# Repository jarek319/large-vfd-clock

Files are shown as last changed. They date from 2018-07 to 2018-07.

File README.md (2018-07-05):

# large-vfd-clock
The largest VFDs I can get my hands on make a really nice clock!

The ILC1-1/8L was another interesting specimen I found while trawling ebay for strange displays.

4 of them with another VFD tube for the colon connect to a Wifi-enabled microcontroller for timekeeping.

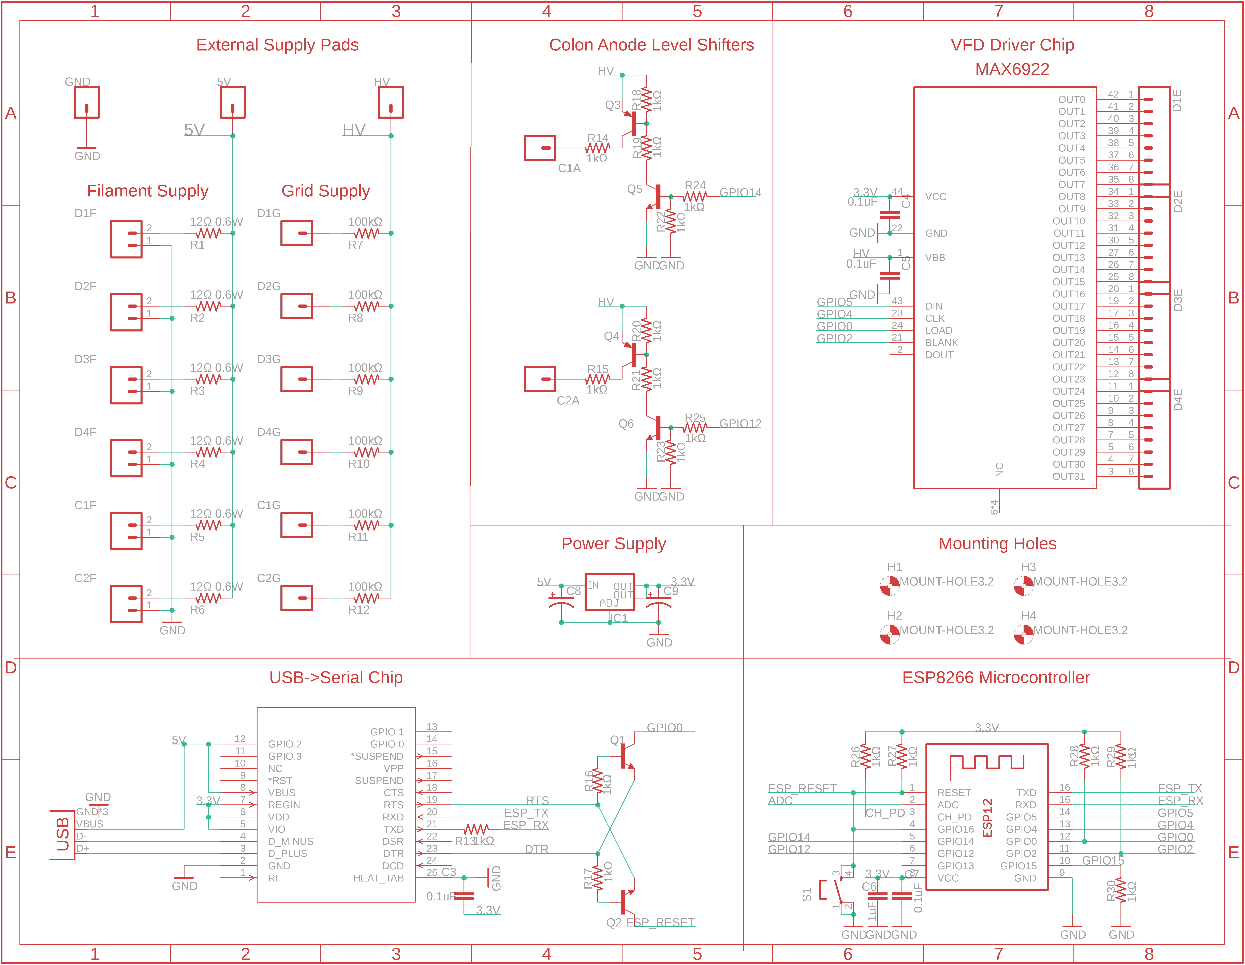
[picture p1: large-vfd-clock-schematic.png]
schematic

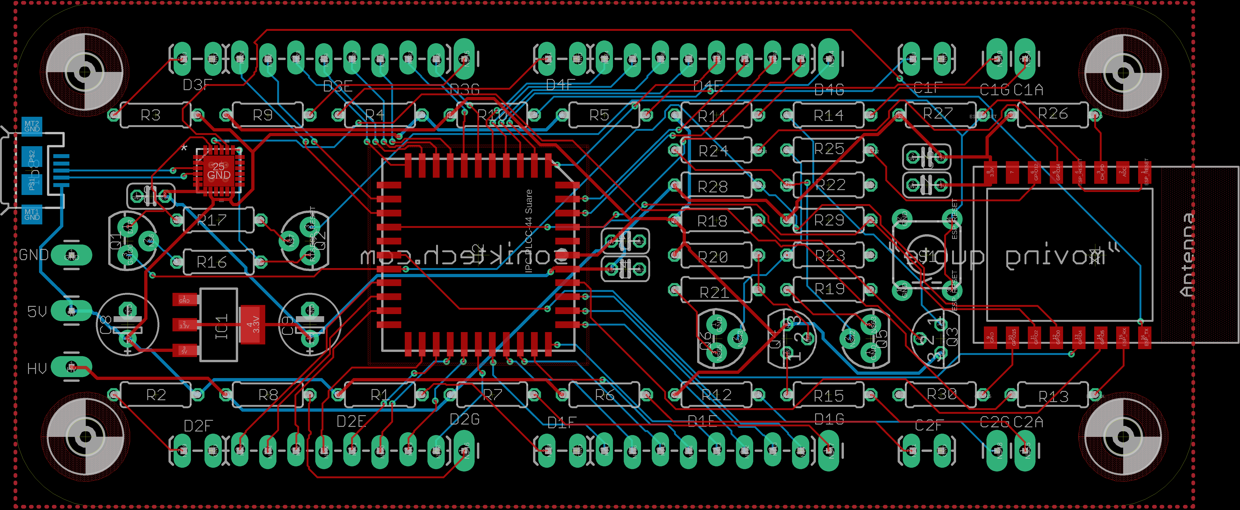
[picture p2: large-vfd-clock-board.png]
board


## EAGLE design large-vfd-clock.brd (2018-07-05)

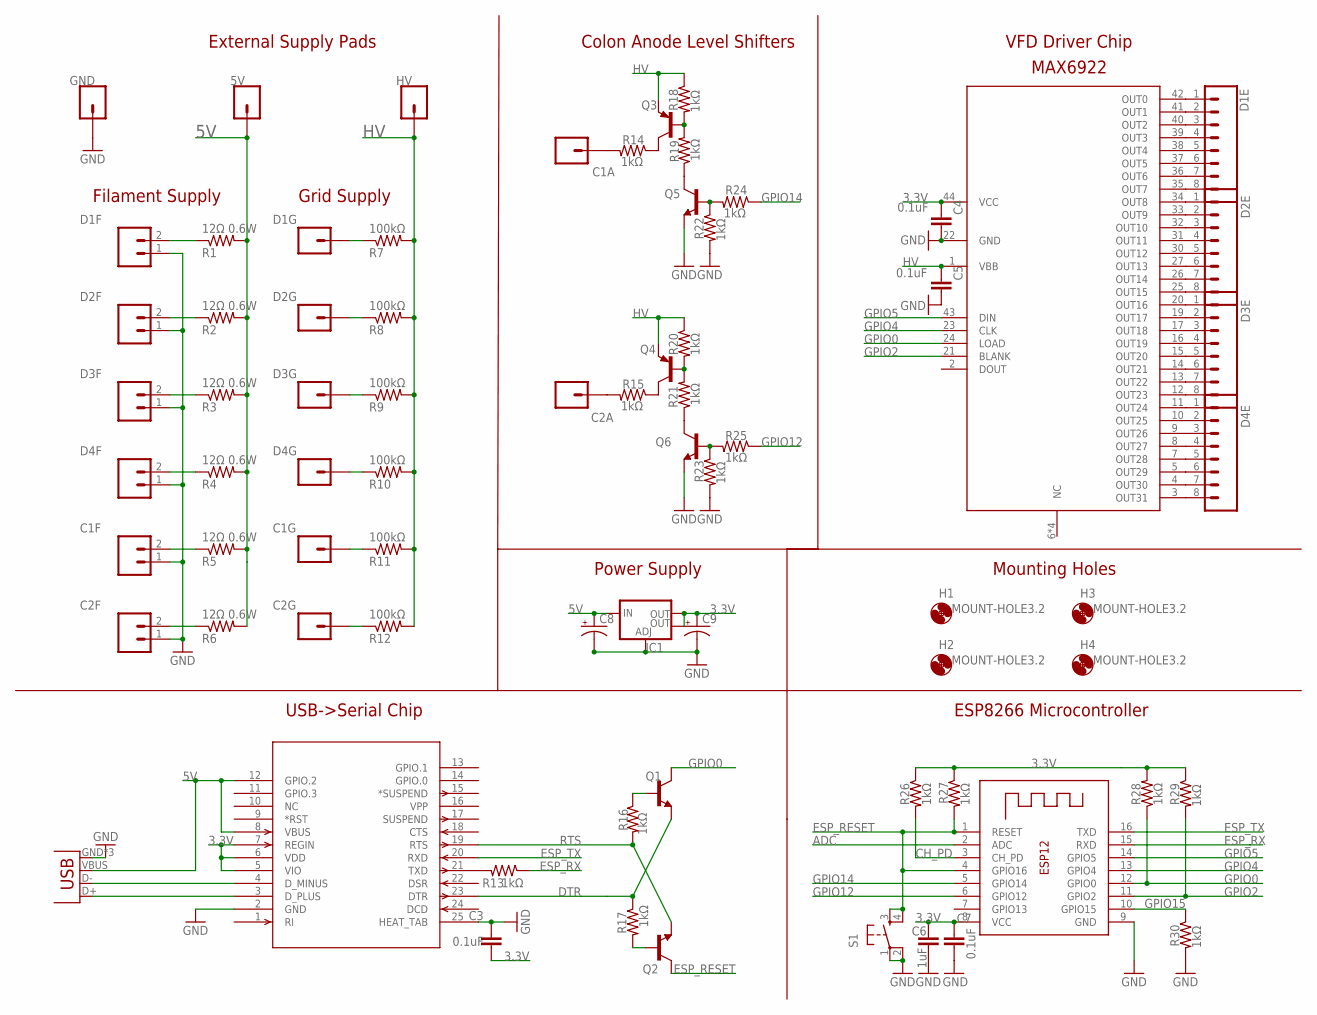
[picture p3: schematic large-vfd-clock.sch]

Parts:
5V: M01PTH_LONGPAD; 1X01_LONGPAD
C1A, C1G, C2A, C2G: M01PTH_LONGPAD; 1X01_LONGPAD
C1F, C2F: M02LOCK_LONGPADS; 1X02_LOCK_LONGPADS
C3, C4, C5, C7: 0.1uF; C025-024X044
C6: 1uF; C025-024X044
C8, C9: CPOL-USE2,5-6E; E2,5-6E
D1E, D2E, D3E, D4E: M08LOCK_LONGPADS; 1X08_LOCK_LONGPADS
D1F, D2F, D3F, D4F: M02LOCK_LONGPADS; 1X02_LOCK_LONGPADS
D1G, D2G, D3G, D4G: M01PTH_LONGPAD; 1X01_LONGPAD
GND: M01PTH_LONGPAD; 1X01_LONGPAD
H1, H2, H3, H4: MOUNT-HOLE3.2; 3,2
HV: M01PTH_LONGPAD; 1X01_LONGPAD
IC1: V_REG_LM1117SOT223; SOT223
JP8: SPARKFUN-CONNECTORS_USB-MICROB
Q1, Q2, Q5, Q6: MMBT2222A; TO-92
Q3, Q4: MMBT3906; TO92
R1, R2, R3, R4, R5, R6: 12Ω 0.6W; 0207/7
R7, R8, R9, R10, R11, R12: 100kΩ; 0207/7
R13, R14, R15, R16, R17, R18, R19, R20, R21, R22, R23, R24, R25, R26, R27, R28, R29, R30: 1kΩ; 0207/7
S1: TAC_SWITCHPTH; TACTILE-PTH
U1: CP2104-GM; QFN24_4X4
U2: MAX6922; PLCC44
X1: ESP-12

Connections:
3.3V: C3.2, C4.1, C6.1, C7.1, C9.+, IC1.2 (OUT), IC1.4 (OUT), R26.1, R27.1, R28.2, R29.1, U1.5 (VIO), U1.6 (VDD), U1.7 (REGIN), U2.44 (VCC), X1.8 (VCC)
5V: 5V.1, C8.+, IC1.3 (IN), JP8.VBUS, R1.2, R2.2, R3.2, R4.2, R5.2, R6.2, U1.8 (VBUS), U1.12 (GPIO.2)
ADC: X1.2 (ADC)
CH_PD: R26.2, X1.3 (CH_PD)
DTR: Q1.1 (E), R17.1, U1.23 (DTR)
D_N1: JP8.D-, U1.4 (D_MINUS)
D_P1: JP8.D+, U1.3 (D_PLUS)
ESP_RESET: Q2.3 (C), R27.2, S1.3, S1.4, X1.1 (RESET), X1.4 (GPIO16)
ESP_RX: R13.1, X1.15 (RXD)
ESP_TX: U1.20 (RXD), X1.16 (TXD)
GND: C1F.1, C2F.1, C3.1, C4.2, C5.2, C6.2, C7.2, C8.-, C9.-, D1F.1, D2F.1, D3F.1, D4F.1, GND.1, IC1.1 (ADJ), JP8.GND, JP8.MT1 (GND), JP8.MT2 (GND), Q5.1 (E), Q6.1 (E), R22.2, R23.2, R30.2, S1.1, S1.2, U1.2 (GND), U1.25 (HEAT_TAB), U2.22 (GND), X1.9 (GND)
GPIO0: Q1.3 (C), R28.1, U2.24 (LOAD), X1.12 (GPIO0)
GPIO2: R29.2, U2.21 (BLANK), X1.11 (GPIO2)
GPIO4: U2.23 (CLK), X1.13 (GPIO4)
GPIO5: U2.43 (DIN), X1.14 (GPIO5)
GPIO12: R25.1, X1.6 (GPIO12)
GPIO14: R24.1, X1.5 (GPIO14)
GPIO15: R30.1, X1.10 (GPIO15)
HV: C5.1, HV.1, Q3.3 (E), Q4.3 (E), R7.2, R8.2, R9.2, R10.2, R11.2, R12.2, R18.1, R20.1, U2.1 (VBB)
unnamed: R13.2, U1.21 (TXD)
unnamed: D1E.1, U2.42 (OUT0)
unnamed: Q1.2 (B), R16.1
unnamed: Q2.2 (B), R17.2
unnamed: D1E.2, U2.41 (OUT1)
unnamed: D1E.3, U2.40 (OUT2)
unnamed: D1E.4, U2.39 (OUT3)
unnamed: D1E.5, U2.38 (OUT4)
unnamed: D1E.6, U2.37 (OUT5)
unnamed: D1E.7, U2.36 (OUT6)
unnamed: D1E.8, U2.35 (OUT7)
unnamed: D2E.1, U2.34 (OUT8)
unnamed: D2E.2, U2.33 (OUT9)
unnamed: D2E.3, U2.32 (OUT10)
unnamed: D2E.4, U2.31 (OUT11)
unnamed: D2E.5, U2.30 (OUT12)
unnamed: D2E.6, U2.27 (OUT13)
unnamed: D2E.7, U2.26 (OUT14)
unnamed: D2E.8, U2.25 (OUT15)
unnamed: D3E.1, U2.20 (OUT16)
unnamed: D3E.2, U2.19 (OUT17)
unnamed: D3E.3, U2.17 (OUT18)
unnamed: D3E.4, U2.16 (OUT19)
unnamed: D3E.5, U2.15 (OUT20)
unnamed: D3E.6, U2.14 (OUT21)
unnamed: D3E.7, U2.13 (OUT22)
unnamed: D3E.8, U2.12 (OUT23)
unnamed: D4E.1, U2.11 (OUT24)
unnamed: D4E.2, U2.10 (OUT25)
unnamed: D4E.3, U2.9 (OUT26)
unnamed: D4E.4, U2.8 (OUT27)
unnamed: D4E.5, U2.7 (OUT28)
unnamed: D4E.6, U2.5 (OUT29)
unnamed: D4E.7, U2.4 (OUT30)
unnamed: D4E.8, U2.3 (OUT31)
unnamed: Q5.2 (B), R22.1, R24.2
unnamed: Q6.2 (B), R23.1, R25.2
unnamed: D4G.1, R10.1
unnamed: D3G.1, R9.1
unnamed: D2G.1, R8.1
unnamed: D1G.1, R7.1
unnamed: C2G.1, R12.1
unnamed: C1G.1, R11.1
unnamed: C1F.2, R5.1
unnamed: C2F.2, R6.1
unnamed: Q4.1 (C), R15.1
unnamed: Q3.1 (C), R14.1
unnamed: C1A.1, R14.2
unnamed: C2A.1, R15.2
unnamed: D1F.2, R1.1
unnamed: D2F.2, R2.1
unnamed: D3F.2, R3.1
unnamed: D4F.2, R4.1
unnamed: Q5.3 (C), R19.1
unnamed: Q3.2 (B), R18.2, R19.2
unnamed: Q6.3 (C), R21.1
unnamed: Q4.2 (B), R20.2, R21.2
RTS: Q2.1 (E), R16.2, U1.19 (RTS)

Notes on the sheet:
Filament Supply
Grid Supply
External Supply Pads
Colon Anode Level Shifters
Mounting Holes
VFD Driver Chip
MAX6922
Power Supply
USB->Serial Chip
ESP8266 Microcontroller

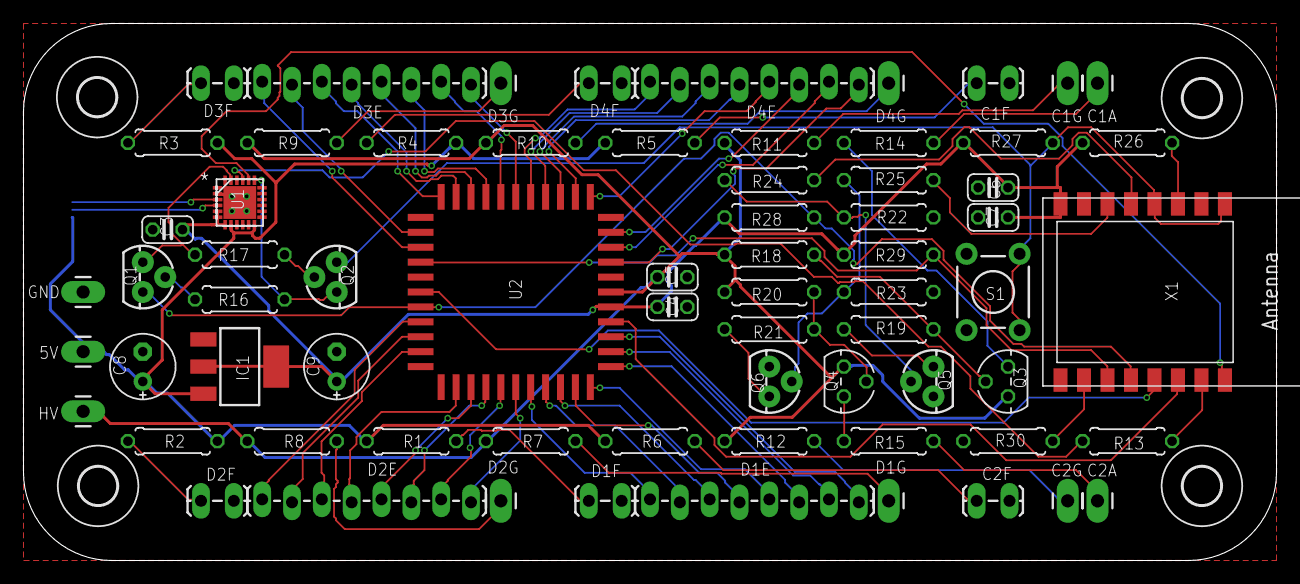
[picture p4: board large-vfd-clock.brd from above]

Board: 2 copper layers, 106.7 x 45.7 mm, 74 parts (1 on the bottom side), 76 nets.

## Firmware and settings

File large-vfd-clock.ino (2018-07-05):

#include <TimeLib.h>
#include <ESP8266WiFi.h>
#include <WiFiUdp.h>
extern "C" {
#include "user_interface.h"
}

#define TOPCOLON 14
#define BOTTOMCOLON 12
#define DIN 5
#define CLK 4
#define LOAD 0
#define BLANK 2

// NTP code adapted from ESP8266 Example code in Arduino core
char ssid[] = "ssid";  //  your network SSID (name)
char pass[] = "pass";       // your network password
unsigned int localPort = 2390;      // local port to listen for UDP packets
IPAddress timeServerIP; // time.nist.gov NTP server address
const char* ntpServerName = "time.nist.gov";
const int NTP_PACKET_SIZE = 48; // NTP time stamp is in the first 48 bytes of the message
byte packetBuffer[ NTP_PACKET_SIZE]; //buffer to hold incoming and outgoing packets
WiFiUDP udp;   // A UDP instance to let us send and receive packets over UDP
const int timeZone = -4;

byte digitArray[] = {
  0b11101101,
  0b00101000,
  0b01110101,
  0b01111100,
  0b10111000,
  0b11011100,
  0b11011101,
  0b01101000,
  0b11111101,
  0b11111100,
  0b11111001,
  0b10011101,
  0b11000101,
  0b00111101,
  0b11010101,
  0b11010001
};

void drawDigits() {
  byte digits[4] = { 0, 0, 0, 0 };
  if ( hour() < 10 ) digits[ 3 ] = digitArray[ 0 ];
  else digits[ 3 ] = digitArray[ hour() / 10 ];
  digits[ 2 ] = digitArray[ hour() % 10 ];
  if ( minute() < 10 ) digits[ 1 ] = digitArray[ 0 ];
  else digits[ 1 ] = digitArray[ minute() / 10 ];
  digits[ 0 ] = digitArray[ minute() % 10 ];

  for ( int i = 0; i < 4; i++ ) {
    digitalWrite( LOAD, LOW );
    for ( int j = 0; j < 8; j++ ) {
      if ( i < 2 ) {
        if ( 1 & ( digits[ i ] >> j )) digitalWrite( DIN, HIGH );
        else digitalWrite( DIN, LOW );
      }
      else {
        if ( 1 & ( digits[ i ] >> ( 7 - j ))) digitalWrite( DIN, HIGH );
        else digitalWrite( DIN, LOW );
      }
      digitalWrite( CLK, HIGH );
      digitalWrite( CLK, LOW );
    }
    digitalWrite( LOAD, HIGH );
  }
}

void setup() {
  pinMode( TOPCOLON, OUTPUT );
  pinMode( BOTTOMCOLON, OUTPUT );
  pinMode( DIN, OUTPUT );
  pinMode( CLK, OUTPUT );
  pinMode( LOAD, OUTPUT );
  pinMode( BLANK, OUTPUT );
  digitalWrite( DIN, LOW );
  digitalWrite( CLK, LOW );
  digitalWrite( LOAD, LOW );
  digitalWrite( BLANK, LOW );
  WiFi.begin(ssid, pass);
  while (WiFi.status() != WL_CONNECTED) delay(500);
  udp.begin(localPort);
  setSyncProvider(getNtpTime);
}

time_t getNtpTime() {
  while (udp.parsePacket() > 0) ; // discard any previously received packets
  WiFi.hostByName( ntpServerName, timeServerIP );  //get a random server from the pool
  sendNTPpacket( timeServerIP ); // send an NTP packet to a time server
  uint32_t beginWait = millis();
  while (millis() - beginWait < 1500) {
    int size = udp.parsePacket();
    if (size >= NTP_PACKET_SIZE) {
      udp.read(packetBuffer, NTP_PACKET_SIZE);  // read packet into the buffer
      unsigned long secsSince1900;
      // convert four bytes starting at location 40 to a long integer
      secsSince1900 =  (unsigned long)packetBuffer[40] << 24;
      secsSince1900 |= (unsigned long)packetBuffer[41] << 16;
      secsSince1900 |= (unsigned long)packetBuffer[42] << 8;
      secsSince1900 |= (unsigned long)packetBuffer[43];
      return secsSince1900 - 2208988800UL + timeZone * SECS_PER_HOUR;
    }
  }
  return 0; // return 0 if unable to get the time
}

// send an NTP request to the time server at the given address
void sendNTPpacket(IPAddress &address)
{
  // set all bytes in the buffer to 0
  memset(packetBuffer, 0, NTP_PACKET_SIZE);
  // Initialize values needed to form NTP request
  // (see URL above for details on the packets)
  packetBuffer[0] = 0b11100011;   // LI, Version, Mode
  packetBuffer[1] = 0;     // Stratum, or type of clock
  packetBuffer[2] = 6;     // Polling Interval
  packetBuffer[3] = 0xEC;  // Peer Clock Precision
  // 8 bytes of zero for Root Delay & Root Dispersion
  packetBuffer[12]  = 49;
  packetBuffer[13]  = 0x4E;
  packetBuffer[14]  = 49;
  packetBuffer[15]  = 52;
  // all NTP fields have been given values, now
  // you can send a packet requesting a timestamp:
  udp.beginPacket(address, 123); //NTP requests are to port 123
  udp.write(packetBuffer, NTP_PACKET_SIZE);
  udp.endPacket();
}
void loop() {
  static time_t prevDisplay = 0; // when the digital clock was displayed
  if (timeStatus() != timeNotSet) {
    if (now() != prevDisplay) { //update the display only if time has changed
      prevDisplay = now();
      drawDigits();
    }
    if ( second() % 2 ) {
      digitalWrite( TOPCOLON, HIGH );
      digitalWrite( BOTTOMCOLON, HIGH );
    }
    else {
      digitalWrite( TOPCOLON, LOW );
      digitalWrite( BOTTOMCOLON, LOW );
    }
  }
}

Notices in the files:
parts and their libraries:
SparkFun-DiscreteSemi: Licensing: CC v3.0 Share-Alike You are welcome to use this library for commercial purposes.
